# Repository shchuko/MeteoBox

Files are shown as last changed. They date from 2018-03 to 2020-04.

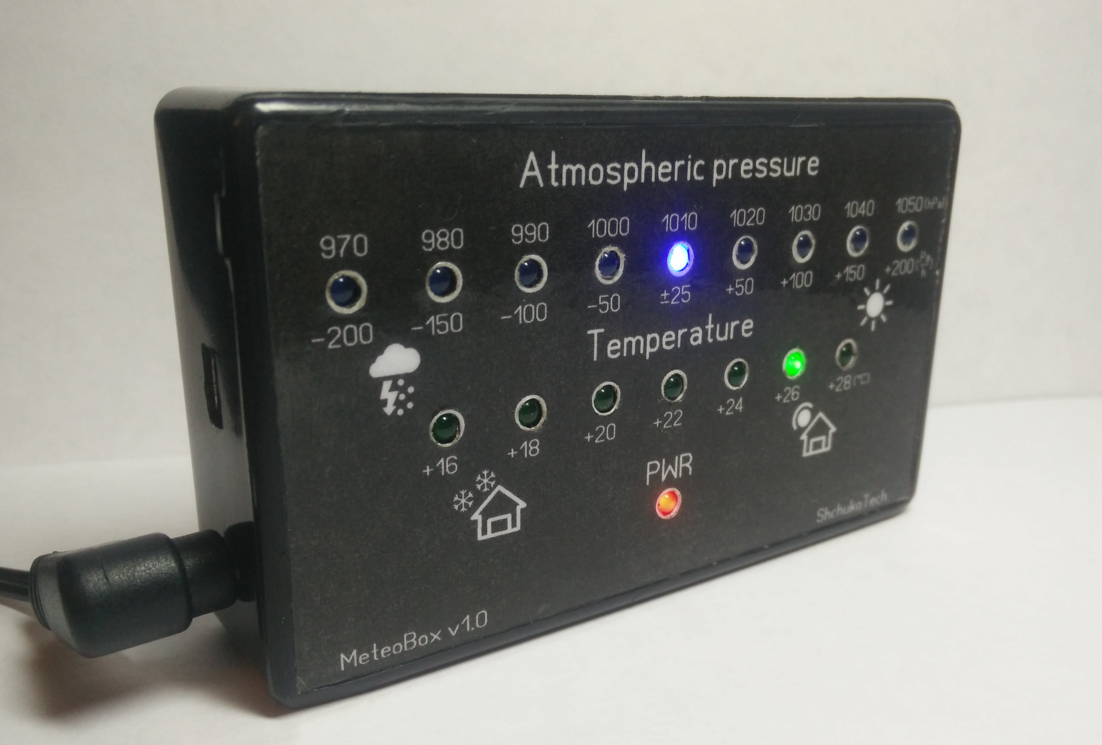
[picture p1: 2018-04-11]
images/1.jpg

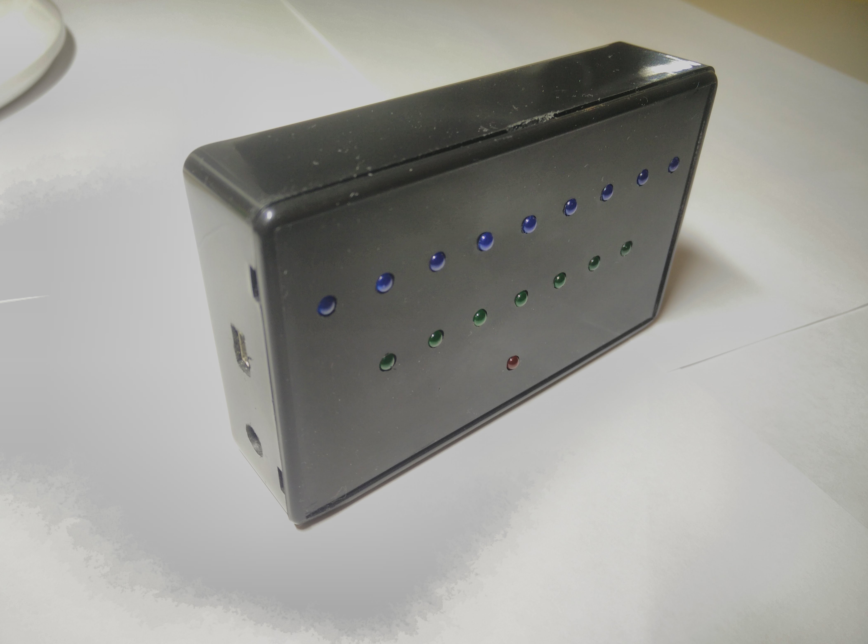
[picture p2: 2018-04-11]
images/3.jpg

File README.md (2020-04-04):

# MeteoBox
##### Simple Arduino-based weather predictor (pressure change tendention calculator). 
------

------
## Device functions
- Display current value of atmospheric pressure (in the range from 970 to 1050 hPa)
- Display current atmospheric pressure change tendention (in the range from -225 Pa/h to +225 Pa/h)
- Display of ambient temperature (in the range from +16°C to +28°C)
- Display of archive readings: atmospheric pressure,  atmospheric pressure change tendention (readings that was made 60 minutes ago)

## More information, user guide

[Uploaded to project wiki](https://github.com/shchuko/MeteoBox/wiki)

## Files

`images/` — Device photos

`src/libs/` — Arduino libraries

`src/sketch/` — Well-commented source code 

`pcbs/` — PCBs drawings, also including components list

`print_templates/` — Front panel and insulator print templates

## Installation
- Install [Arduino IDE](https://www.arduino.cc/en/Main/Software)
- Install [Optiboot bootloader](https://github.com/Optiboot/optiboot#to-install-into-the-arduino-software) into the Arduino software 
- [Burn Optiboot bootloader onto your Arduino Nano board](https://github.com/Optiboot/optiboot#to-burn-optiboot-onto-an-arduino-board)*
- Install the libraries `src/libs/` into the Arduino software 
- Flash the sketch `src/sketch/` into the Arduino board using Arduino IDE
- Connect the the rest of electronic components from the list `pcbs/Full components list.txt`. You can use PCBs or Bread board for this. I did not make a circuit, but using PCB drawings it's easy to figure out the connection of electronic components
- Power the board on!

*if you don't have an ability to burn Optiboot bootloader, comment out this lines in the source code:
```c
#include <avr/wdt.h> // Avr watchdog timer library 
wdt_disable( );
wdt_enable( WDTO_8S ); // setting up watchdog timer 
wdt_reset( ); // resetting watchdog timer
```

## Links
[Optiboot bootloader](https://github.com/Optiboot/optiboot)

[Arduino Software](https://www.arduino.cc/en/Main/Software)

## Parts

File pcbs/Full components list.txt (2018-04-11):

Components: controller

1. BMP180 Barometer
2. C1 100mkF
3. C2 0.1 mkF
4. D1 Nano v3
5. G1 DC Jack
6. LDR1  
7. R0 10k (SMD)
8. SB1 TTP223
9. SB2 RST
10. X1

Components: indication

1. LED1 Blue
2. LED2 Blue
3. LED3 Blue
4. LED4 Blue
5. LED5 Blue
6. LED6 Blue
7. LED7 Blue
8. LED8 Blue
9. LED9 Blue
10. LED10 Green
11. LED11 Green
12. LED12 Green
13. LED13 Green
14. LED14 Green
15. LED15 Green
16. LED16 Green
17. LED17 Red
18. R1 6.8k
19. R2 6.8k
20. R3 6.8k
21. R4 6.8k
22. R5 6.8k
23. R6 6.8k
24. R7 6.8k
25. R8 6.8k
26. R9 6.8k
27. R10 20k
28. R11 20k
29. R12 20k
30. R13 20k
31. R14 20k
32. R15 20k
33. R16 20k
34. R17 3.3k

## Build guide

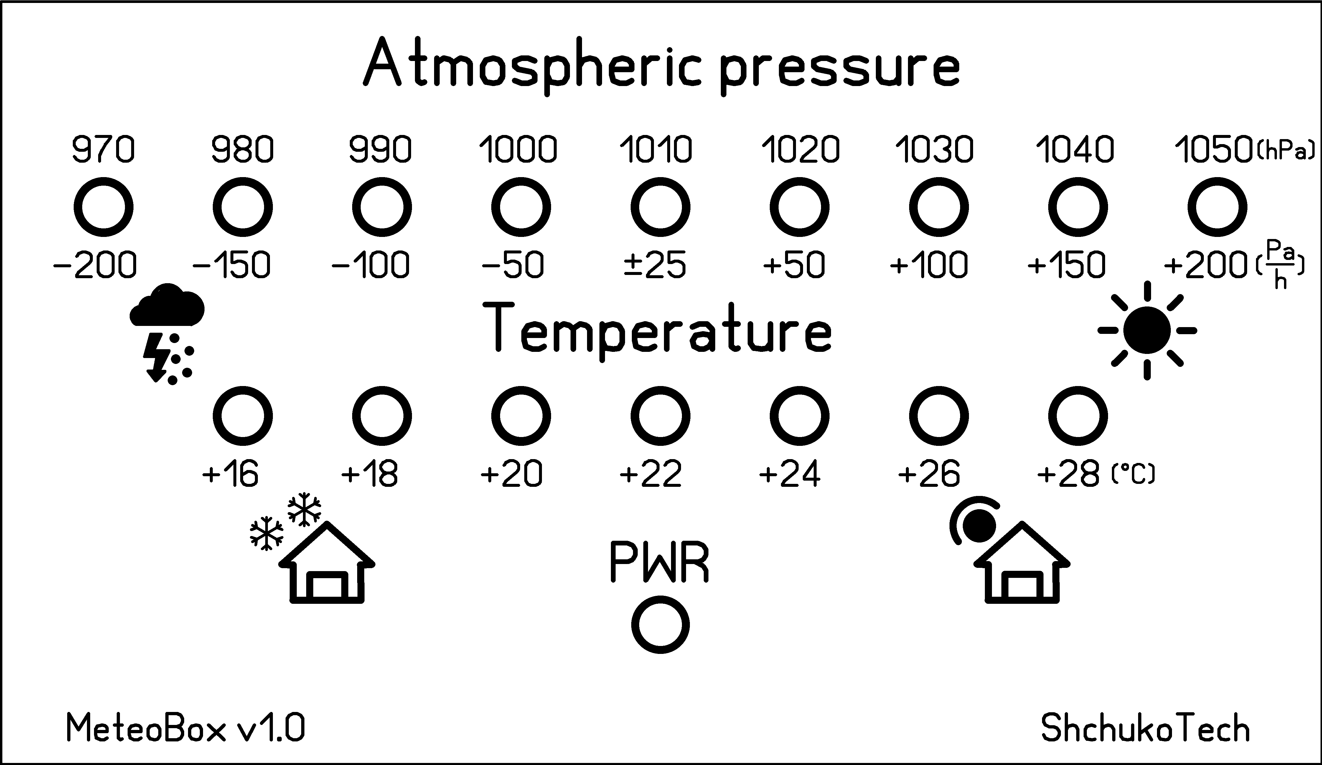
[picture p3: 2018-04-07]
print_templates/front_panel/bmp/front_panel_inv.bmp

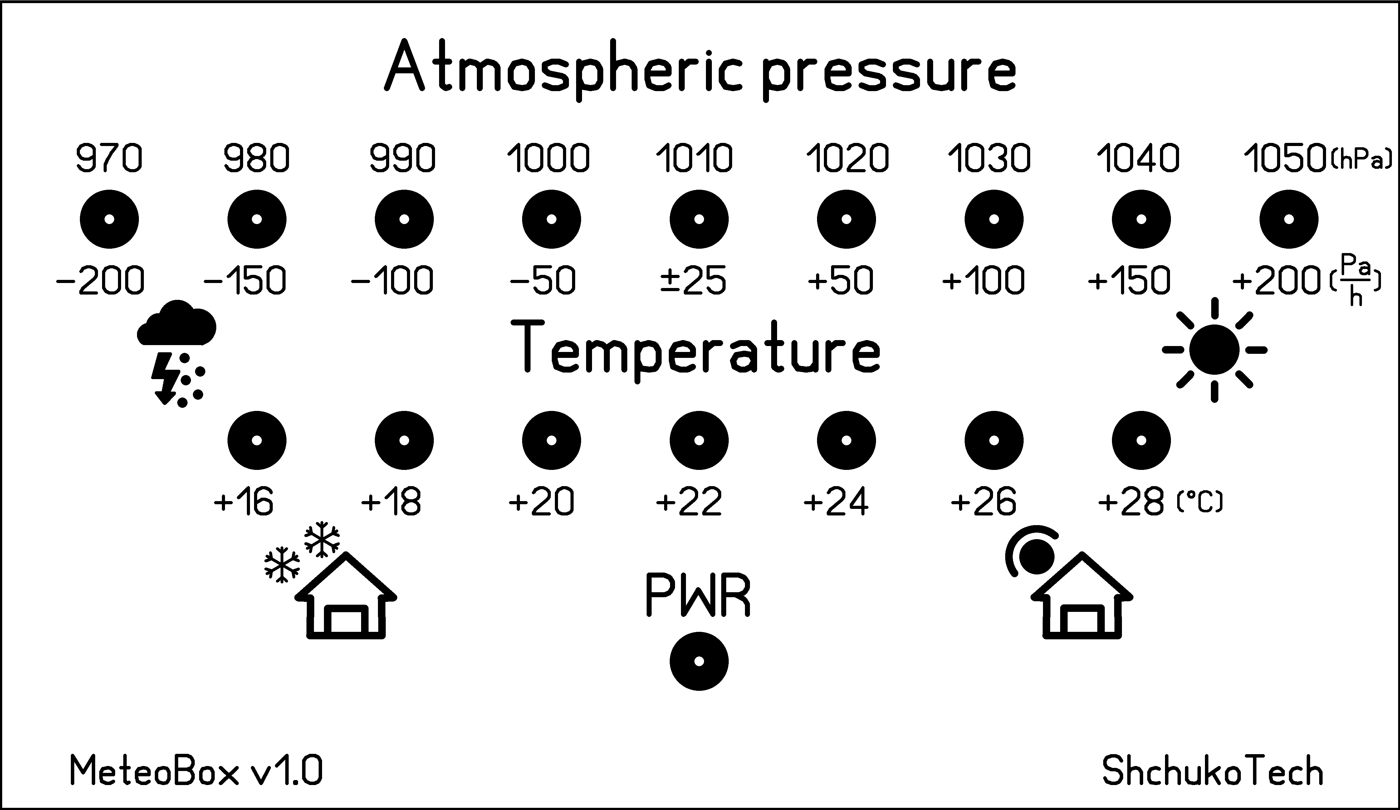
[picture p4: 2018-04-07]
print_templates/front_panel/bmp/front_panel_drill_inv.bmp

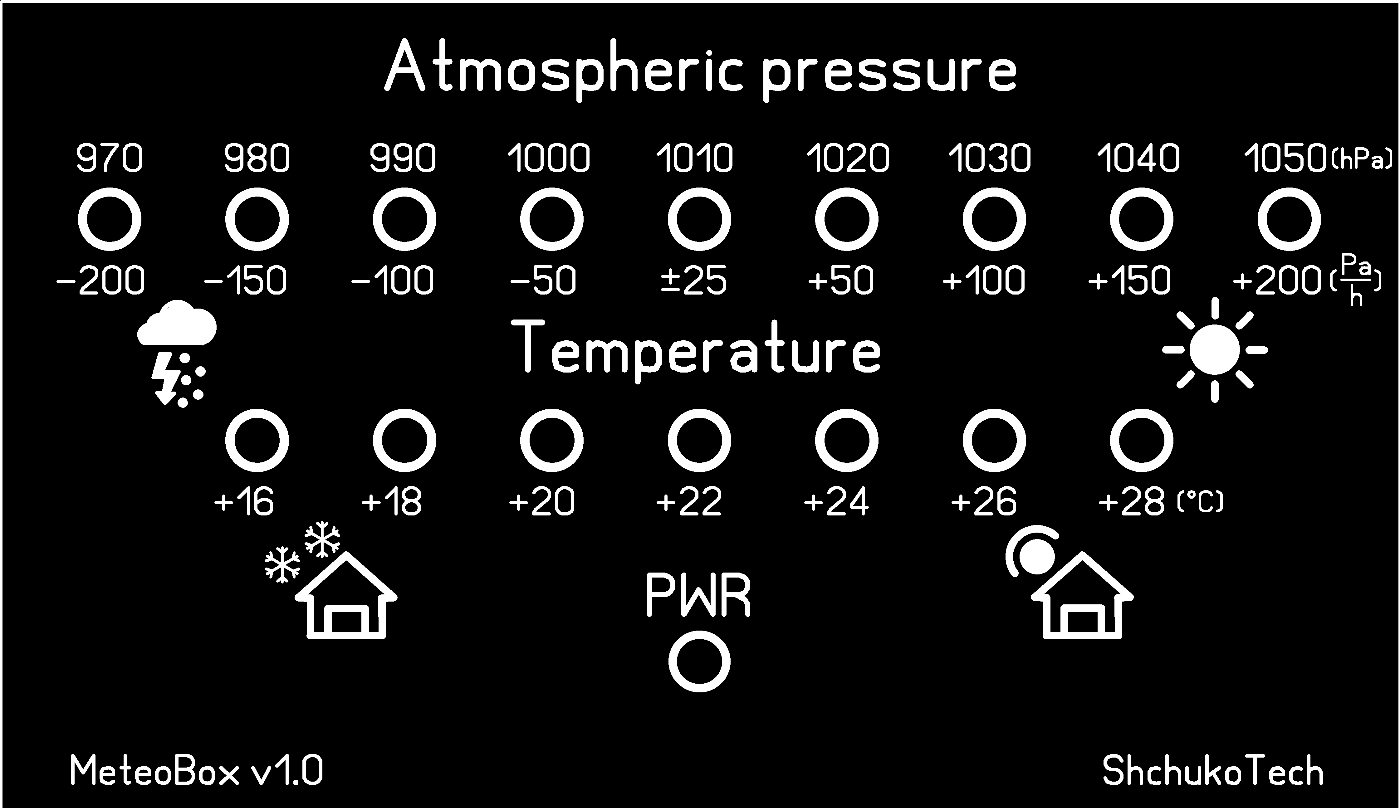
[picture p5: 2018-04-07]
print_templates/front_panel/bmp/front_panel.bmp

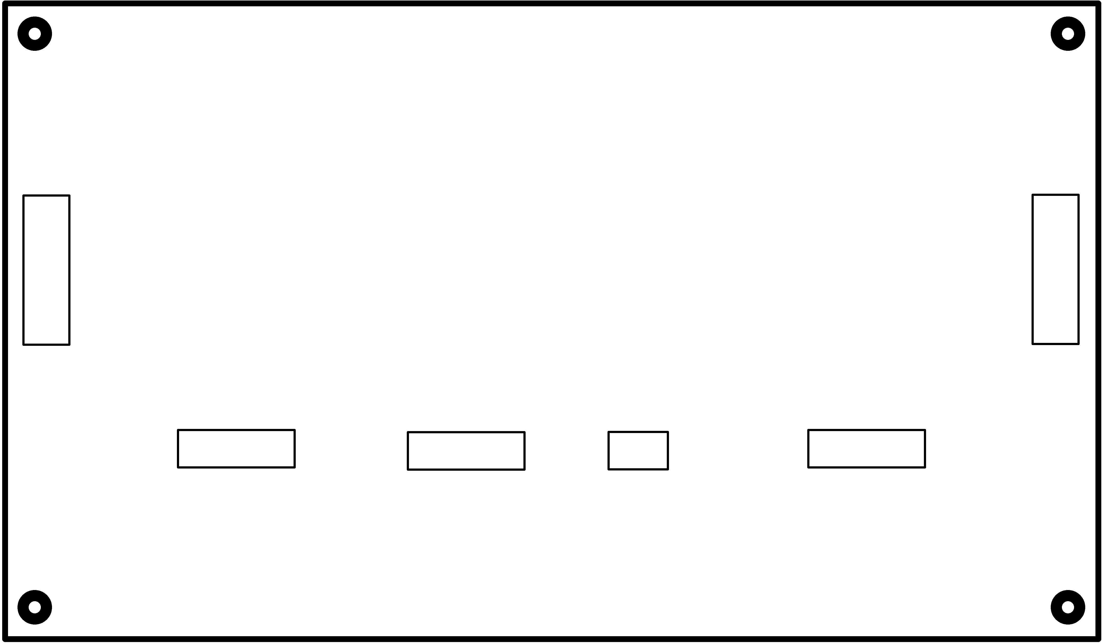
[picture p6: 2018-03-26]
print_templates/insulator/bmp/insulator_96x56mm.bmp

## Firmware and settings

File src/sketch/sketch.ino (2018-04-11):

/* MeteoBox  
 *  Version: 1.0.2
 *  Author: Vladislav Yaroshchuk (Shchuko)
 *  Created: 2018
 *  Website: https://github.com/shchuko 
 *  
 *  11/04/2018 shchuko: Watchdog timer added. Bug fixes
 *                     
 */

/* PIN CONFIGURATION
 *   D1:  L PWR 
 *   D0:  L +22*C
 *   D2:  L +-25 Pa/h (also: 1010hPa)
 *   D3:  TTP223 BUTTON 
 *   D4:  L +50 Pa/h (also: 1020hPa)
 *   D5:  L +100 Pa/h (also: 1030hPa)
 *   D6:  L +150 Pa/h (also: 1040hPa)
 *   D7:  L +200 Pa/h (also: 1050hPa)
 *   D8:  L -50 Pa/h (also: 1000hPa)
 *   D9:  L -100 Pa/h (also: 990hPa)
 *   D10: L -150 Pa/h (also: 980hPa)
 *   D11: L -200 Pa/h (also: 970hPa)
 *   D12: L +16*C
 *   D13: L +18*C
 *   D14: L +20*C
 *   D15: L +24*C
 *   D16: L +26*C
 *   D17: L +28*C
 *   A4: I2C BUS
 *   A5: I2C BUS
 *   A6: N/C
 *   A7: Light-dependent resistor (LDR)
 * L - LED
 * N/C - Not connected
 */

#include <Adafruit_BMP085.h>  // Barometr BMPxxx library
#include <EEPROM.h> // EEPROM library
#include <avr/wdt.h>  // Avr watchdog timer library

// -----Temperature indication pins-----
#define L_16C   12 
#define L_18C   13
#define L_20C   14
#define L_22C   0
#define L_24C   15
#define L_26C   16
#define L_28C   17

// -----Pressure indication pins----
#define L_25P   2 
#define L_50P   4
#define L_100P  5
#define L_150P  6
#define L_200P  7
#define L_50PM  8
#define L_100PM 9
#define L_150PM 10
#define L_200PM 11

// -----Pressure forecast-----
#define FORECAST_VAL_NUMBER       7   // Number of saved values
#define DATA_UPDATE_INTERVAL      5   // ... in minutes 
#define FORECAST_UPDATE_INTERVAL  10  // ... in minutes
                                      // Condition: FORECAST_UPDATE_INTERVAL % DATA_UPDATE_INTERVAL = 0 !!!

// -----Other-----
#define LDR     A7  // Light-dependent resistor
#define L_PWR   1   // Power LED
#define Pa_to_hPa 0.01 
#define NIGHT_FLAG_EEPROM_ARRD 0

// -----Controll button preferences-----
#define BT1_PIN  3 // Interrupt number
#define L_PWR_BTN_BLINK_NUMBER 4 // PWR LED blinks count if button was touched

// -----Classes------
class LedString { // LED string class 
                  // Contains methods for controlling the 
                  // LED string connected to the digital pins (max is 255)
private:

  uint8_t*  LED_string  = NULL;
  uint8_t*  pins = NULL;
  uint8_t   number = 0;

  uint8_t byte_num( uint8_t pin_num ) { // byte number in allocated memory
    pin_num++;
    return ( pin_num / 8 + ( pin_num / 8.0 > pin_num / 8 ) - 1 );
  }

  uint8_t bit_pos( uint8_t pin_num ) {  // bit position in byte 
    return ( pin_num - pin_num / 8 * 8 ); 
  }
  
public: 

  LedString( uint8_t _number ) {
    number = _number; // saving the number of LEDs
    pins = new uint8_t[ number ];  // allocate memory for pins numbers

    uint8_t byte_number = _number / 8 + ( _number / 8.0 > _number / 8 );  // calculating a sufficient number of memory (in bytes)
    LED_string = new uint8_t[ byte_number ]; // allocate memory for pins states
    
    for ( uint8_t i = 0; i < byte_number; i++ ) // clearing the memory
      LED_string[ i ] = 0;  
  } 

  ~LedString( ) { // never-called destructor ;)
    delete[ ] pins;
    pins = NULL;

    delete[ ] LED_string;
    LED_string = NULL;
  }
  void init_pin( uint8_t pin_arduino, uint8_t pin_num ) {
    pinMode( pin_arduino, OUTPUT ); // set pin mode as OUTPUT 
    digitalWrite( pin_arduino, 0 ); // set pin state as "0"
   
    pins[ pin_num ] = pin_arduino;
  }
  
  bool get_pin( uint8_t pin_num ) { // returns pin state
    return ( ( LED_string[ byte_num( pin_num ) ] >> bit_pos( pin_num ) ) & ( 1 << 0 ) );
  }
 
  void set_pin( uint8_t pin_num, bool pin_state ) { // set state for pin
    bool old_pin_state = get_pin( pin_num );
    
    if ( pin_state != old_pin_state ) {
      digitalWrite( pins[ pin_num ], pin_state );
      
      if ( pin_state )  // if new state is "1" writing...
        LED_string[ byte_num( pin_num ) ] |= ( 1 << bit_pos( pin_num ) );
      else  // else if new state is "0" writing...
        LED_string[ byte_num( pin_num ) ] &= ~( 1 << bit_pos( pin_num ) );
    }
    
  }

  uint8_t get_byte( uint8_t _byte_num ) { // returns full byte
    return LED_string[ _byte_num ];
  }
  
  void set_byte( uint8_t _byte_num, uint8_t new_byte ) { // set full byte 
    if ( new_byte != LED_string[ _byte_num ] ) {
      LED_string[ _byte_num ] = new_byte;
      for ( uint8_t i = 0; i < 8; i++ )
        if ( 8 * _byte_num + i < number )
          digitalWrite( pins[ 8 * _byte_num + i ],(( new_byte >> i ) & ( 1 << 0 )) );
        else
          break;
    }
  }

  void on( ) {
    for ( uint8_t i = 0; i < number; i++ ) {
      if ( !(i % 8) ) 
         LED_string[ i / 8 ] = 0xFF;
      digitalWrite( pins[ i ],  1 );
    }
  }

  void off( ) {
    for ( uint8_t i = 0; i < number; i++ ) {
      if ( !(i % 8) ) 
         LED_string[ i / 8 ] = 0;
      digitalWrite( pins[ i ],  0 );
    }
  }
  
};

class MedianFilter {  // Median filter class ( all arguments > 0 )
private:
  uint32_t *values = NULL; // pointer at the first saved value
  uint8_t val_number = 0; // number of values
  
  uint8_t new_val_pos = 0;  // position of new value in values[ ] ( used in function new_val )
  
  uint32_t result = 0; // result value 

  void calculate( ) { // calculating median value
    // bubble sort algorithm
    for( uint8_t i = 0; i < val_number - 1; i++ )  
      for( uint8_t j = i + 1; j < val_number; j++ )
      { 
        if( values[ i ] > values[ j ] )
        {
          uint32_t term_val = values[ i ];
          values[ i ] = values[ j ];
          values[ j ] = term_val;
        }
      }
    result = values[ ( uint8_t )(( val_number - 1 ) / 2 ) ]; // saving median value
  }
  
public:
  MedianFilter( uint8_t _val_number ) {
    val_number = _val_number; // saving the number of values
    values = new uint32_t[ _val_number ]; // allocate memory for saving values    
  }

  ~MedianFilter( ) {  // never-called destructor
    delete[ ] values;
    values = NULL;
  }
  void init( uint32_t val ) {
    for ( uint8_t i = 0; i < val_number; i++ )
      values[i] = val;
    result = val;
  }
  
  bool new_val( uint32_t val ) { // updating (saving) new value
                                        // returning 1 - updating complete, 0 - updating not complete 
      values[ new_val_pos ] = val; // saving new value
      new_val_pos++; // incriminate value pos counter
    if ( new_val_pos == val_number )  // if all values saved
    {
      new_val_pos = 0; 
      calculate( ); // calculating median value
      return 1; // returning 1
    } 
    // else 
    return 0; // returning 0
  } 

  uint32_t get_result( ) {  // returning calculated median value
    return result;
  }

};

class PressureForecast {
private:
  uint32_t   *pressure = NULL;        // pointer for dynamic memory allocation for pressure
  int16_t    *history  = NULL;        // pointer for dynamic memory allocation for forecast history
  int16_t    change_hour;             // pressure change forecast (Pa/h)
  uint8_t    measurement_number;       // measurement number used for calculating forecast
  uint16_t   measurement_interval;    // pressure update interval (in minutes)
  uint8_t    meas_updts_counter = 1;  // pressure updates counter
  
  void calculate( ) {   // pressure change calculatioin
                        // using least squares fit
    uint32_t sumx = 0;  
    uint32_t sumy = 0;
    uint32_t sumx2 = 0;
    uint32_t sumxy = 0;
    for ( uint8_t i = 0; i < measurement_number; i++ ) {
      sumx += i;
      sumy += pressure[ i ];
      sumx2 += i * i;
      sumxy += i * pressure[ i ];
    }
    double a;
    a = measurement_number * sumxy;
    a -= sumx * sumy;
    a = ( double )a / ( measurement_number * sumx2 - sumx * sumx );
    change_hour = round( a * 60 / measurement_interval ); // pressure change forecast (Pa/h)
  }
  
public:
  void set( uint32_t _pressure ) {  // set new pressure value
    for ( uint8_t i = 0; i < measurement_number - 1; i++ ) {// shifting old saved values
      pressure[ i ] = pressure[ i + 1 ];  
      history[ i ] = history[ i + 1 ];
    }
    pressure[ measurement_number - 1 ] = _pressure;  // saving new value
    calculate( ); // re-calculating  forecast
    
    history[ measurement_number - 1 ] = change_hour;
    
    if ( meas_updts_counter < measurement_number )  // if full update did not complete
      meas_updts_counter++; 
  }

  bool is_update( ) {  // returns 1 if full update completed
    return ( meas_updts_counter >= measurement_number );
  }
  
  int16_t get_history_forecast( ) { // returns forecast history value
    return history[ 0 ];
  }

  uint32_t get_history_pressure( ) { // returns pressure history value
    return pressure[ 0 ];
  }

  int32_t get_forecast( ) { // returns pressure change forecast (Pa/h)
    return change_hour;
  }
  
  void begin( uint32_t _pressure )  // set first pressure value (in Pa)
  {
    for ( uint8_t i = 0; i < measurement_number; i++ ) {
      pressure[ i ] = _pressure;
      history[ i ] = 0;
    }
  }
  
  PressureForecast( uint8_t  _measurement_number,         // measurement number used for calculating forecast
                     uint16_t  _measurement_interval ) {  // pressure update interval (in minutes)
    // dynamic memory allocation
    pressure = new uint32_t [ _measurement_number ];
    history = new int16_t [ _measurement_number ];
    
    measurement_number = _measurement_number;
    measurement_interval = _measurement_interval;
  }  

  ~PressureForecast( ) {  // never-called destructor ;)
    delete[ ] pressure;
    delete[ ] history;

    pressure = NULL;
    history = NULL;
  }
  
};

class TTP223 {  // TTP223 sensor click handler
                // based on  millis( ) func.
                // Three modes of recognition of button pressing:
                // [short click], [double click], [long press]
private:
  void ( *long_press )( void );    // pointer to a long-press action function 
  void ( *short_click )( void );   // pointer to a short-click action function
  void ( *double_click )( void );  // pointer to a double-click action function
    
  uint8_t pin = 0;  // pin number

  bool touch_flag = 0;  
  bool double_click_flag = 0;
  
  bool last_state = 0;
  
  uint64_t press_time = 0; // last button touching time 

public:
  
  TTP223( uint8_t _pin,                     // interrupt number (0 or 1)
          void ( *_short_click )( void ),   // pointer to the button short-click function
          void ( *_double_click )( void ),  // pointer to the button double-click function
          void ( *_long_press )( void ) ) { // pointer to the button long-press function
    short_click  = _short_click; 
    double_click = _double_click;
    long_press   = _long_press;
   
    pin = _pin;
  }

  ~TTP223 ( ) { // never-called destructor ;)
    short_click = NULL;
    double_click = NULL;
    long_press = NULL;
  }

  void loop_func( ) { // button click handler
    if ( digitalRead( pin ) != last_state ) { // if buton pin state have changed
      last_state = !last_state; // saving new state

      if ( last_state ) { // if button pressed
        press_time = millis( ); // saving button press time
        touch_flag = 1; // press (click) flag
      } 
    }
    
    if ( touch_flag && millis( ) - press_time > 700 ) {  // if 700 ms least after last click
      long_press( );  // long-press function
      touch_flag = 0; 
    }

    if ( double_click_flag && millis() - press_time  > 400 ) {  // if double-click time has expired 
                                                                // (it's not enough time to double-click
                                                                // - more than 400 ms left)
      double_click_flag = 0;                                   
                
      short_click( ); // short-click function
    }
    
    if ( touch_flag ) // if the button was pressed
      if ( double_click_flag ) {  // if double-click is possible
        double_click_flag = 0;  
        touch_flag = 0; 
        double_click( );  // double-click function
        
      } else if ( !last_state ) { // else if button was released
        touch_flag = 0;
          
        if ( millis( ) - press_time <= 400 ) // if it's enough time to double-click 
          double_click_flag = 1;  // setting up double-click flag
        else // else if it's not enough time to double-click
          short_click( ); // short-click function
      }
  }
};

// -----Button functions-----
void button_long_press( );
void button_short_click( );
void button_double_click( );

// -----Objects------
LedString prs_led( 9 ); // pressure indication string - 9 LEDs
LedString temp_led( 7 );  // temperature indication string - 7 LEDs

Adafruit_BMP085 bmp;  // BMPxxx sensor
PressureForecast forecast( FORECAST_VAL_NUMBER, FORECAST_UPDATE_INTERVAL );  //  pressure change forecast

MedianFilter avr_pressure( 10 );  // median filter for BMP180 barometer data - 10 values save
MedianFilter avr_luminosity( 10 );  // median filter for light-dependent resistor data - 10 values save

TTP223 button( BT1_PIN, button_short_click, button_double_click, button_long_press ); // TTP223 button

// -----Global variables-----
uint32_t pressure = 0;       // current pressure in hPa
int16_t  temperature = 0;    // current temperature in *C
uint16_t luminosity = 1023;  // current illumination value (from ADC: 0..1023)

bool     _forecast_actual_flag = 0;      // forecast actual flag

uint8_t  _forecast_range = 4;            // forecast range (for LED string)
uint8_t  _forecast_range_blink_mode = 4; // forecast blink mode 

uint8_t  _forecast_h_ago_range = 4;            // forecast range 1 hour ago (for LED string)
uint8_t  _forecast_h_ago_range_blink_mode = 4; // forecast blink 1 hour ago mode 

uint8_t  _pressure_range = 4;            // pressure range (for LED string)
bool     _pressure_range_blink_flag = 0; // pressure range blink flag

uint8_t  _pressure_h_ago_range = 4;            // pressure range 1 hour ago (for LED string)
bool     _pressure_h_ago_range_blink_flag = 0; // pressure range 1 hour ago blink flag

uint8_t  _temp_range = 3;            // temperature range (for LED string)
bool     _temp_range_blink_flag = 0; // temperature range blink flag

bool night_mode_enable = 1; // night mode flag (0 - enable, 1 - disable)
bool night_mode_state = 0;  // current situation flag (0 - LEDs enable, 1 - LEDs disable)

bool     temprary_touch_awake = 0; // system awaking from the night mode if button touched
uint64_t temprary_touch_awake_counter = 0;  

bool display_mode = 0;  // genegal diplay mode
                        // 0 - current data, 1 - data 1h ago 
bool prs_disp_mode = 0; // pressure display mode
                        // 0 - current pressure (hPa), 1 - pressure forecast display (Pa/h)

uint64_t display_return_counter = 0;  // time counter to return to current 
                                      // data display & current pressure display
uint8_t  display_return_mode = 0; // return mode:
                                  // 0 - disable
                                  // 1 - return from forecast display to the current pressure display
                                  // 2 - return from 1h ago data display to the current data display

uint64_t button_blink_counter_time = 0; // button touch - PWR LED blink time counter
uint8_t  button_blink_counter = L_PWR_BTN_BLINK_NUMBER; // button touch - PWR LED blink(s) counter - max is L_PWR_BTN_BLINK_NUMBER

// -----Functions-----
void serial_test_func( ) {
  Serial.println( );
  Serial.println( "******************************" );
  Serial.println( "Data update..." );
  Serial.println( );
  
  Serial.print( "Pressure: ");
  Serial.println( pressure );
  Serial.print(" Pressure range: ");
  Serial.println( _pressure_range );
  Serial.print(" Pressure range blink flag: ");
  Serial.println( _pressure_range_blink_flag );

  Serial.print( "Temperature: ");
  Serial.println( temperature );
  Serial.print(" Temperature range: ");
  Serial.println( _temp_range );
  Serial.print(" Temperature range blink flag: ");
  Serial.println( _temp_range_blink_flag );

  Serial.print( "Forecast: " );
  Serial.println( forecast.get_forecast( ) );
  Serial.print( " Forecast actual flag: " );
  Serial.println( _forecast_actual_flag );
  Serial.print( " Forecast range: " );
  Serial.println( _forecast_range );
  Serial.print( " Forecast range blink mode: " );
  Serial.println( _forecast_range_blink_mode );
  
}

void serial_flag_test_func( ) {
  Serial.println( );
  Serial.println( "******************************" );
  Serial.println( "Button touched..." );
  Serial.println( );
  
  Serial.print( "Night mode enable flag: " );
  Serial.println( night_mode_enable );

  Serial.print( "Display mode flag: " );
  Serial.println( display_mode );
  
  Serial.print( "Pressure display mode flag: " );
  Serial.println( prs_disp_mode );
}

void button_short_click( ) {
  button_blink_counter = 0; // setting buton blink counter to zero
  digitalWrite( L_PWR, 1 ); // switching on PWR LED
  
  if ( !night_mode_state || temprary_touch_awake )  // if LEDs are enabled or it is temprary awake
  {
    prs_disp_mode = !prs_disp_mode;
    
    if ( display_mode ) { // if it is 1h ago data display 
      
      display_return_mode = 2;  // changing return timer mode 
      display_return_counter = millis( ); // updating time counter
    } 
  
    if ( prs_disp_mode && !display_mode ) {  // if it's switching to the forecast display mode within current data display
      display_return_mode = 1;  // changing return timer mode 
      display_return_counter = millis( ); // updating time counter
    } else if ( display_return_mode && !display_mode ) {  // else if it's current data display within enabled return timer
      display_return_mode = 0;  // disabling timer
    }

    // if it's it is temprary awake, updating awake timer
    if ( temprary_touch_awake ) temprary_touch_awake_counter = millis( );
    
  } else if ( night_mode_state && night_mode_enable ) { // else if luminosity is low, LEDs are disabled
    display_mode = 0; // switching to the  current data fisplay
    prs_disp_mode = 0;  // switching pressure display mode to the pressure mode
    
    temprary_touch_awake = 1; // waking up system for several seconds
    temprary_touch_awake_counter = millis( );
  } 
  
  temp_led.off( );  // clearing temperature LED string
  prs_led.off( );   // clearing pressure LED string
  //serial_flag_test_func( );
}

void button_double_click( ) { 
  button_blink_counter = 0; // setting buton blink counter to zero
  digitalWrite( L_PWR, 1 ); // switching on PWR LED
  
  if ( ( !night_mode_state || temprary_touch_awake ) && _forecast_actual_flag )  // if LEDs are enabled or it is temprary awake
  {                                                                              // and 1h left after powering on system
    prs_disp_mode = 0;  // switching pressure display mode to a pressure mode
    
    if ( display_mode = !display_mode ) { // if it is switching to 1h ago data display 
      display_return_mode = 2;  // changing return timer mode 
      display_return_counter = millis( ); // updating time counter
    } else {
      display_return_mode = 0;
    }

    // if it's it is temprary awake, updating awake timer
    if ( temprary_touch_awake ) temprary_touch_awake_counter = millis( );
    
  } else if ( night_mode_state ) { // else if luminosity is low, LEDs are disabled
    display_mode = 0; // switching to the  current data fisplay
    prs_disp_mode = 0;  // switching pressure display mode to the pressure mode
    
    temprary_touch_awake = 1; // waking up system for several seconds
    temprary_touch_awake_counter = millis( );
  } 
  
  temp_led.off( );  // clearing temperature LED string
  prs_led.off( );   // clearing pressure LED string
  //serial_flag_test_func( );
}
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
void loop( ) {
  wdt_reset( ); // resetting watchdog timer
  
  button.loop_func( ); 
  
  luminosity_upd( luminosity ); //updating luminosity
  
  // nigth mode switcher with gisteresis:
  if ( night_mode_enable ) {
    if ( luminosity < 95 )  // if luminosity is low
      night_mode_state = 1;
    else if ( luminosity > 127 )  // if luminosity is high
      night_mode_state= 0;
  } else if ( night_mode_state ) {
    night_mode_state = 0;
  }

  static uint64_t data_upd_counter = millis( ); // data update time counter  
  static uint64_t forecast_upd_counter = millis( ); // data update time counter

  
  if ( millis( ) - data_upd_counter  >= DATA_UPDATE_INTERVAL * 60000 ) { // if it's time to update data 
    pressure = pressure_upd( );  // updating pressure
    _pressure_range = pressure_range( round( pressure * Pa_to_hPa ), _pressure_range_blink_flag ); // updating pressure range
    
    temperature = round( bmp.readTemperature( ) - 3 ); // updating temperature
    _temp_range = temp_range( temperature, _temp_range_blink_flag );  // updating temperature range

    
    if ( millis( ) - forecast_upd_counter >= FORECAST_UPDATE_INTERVAL * 60000 ) {  // if it's time to update forecast
      forecast.set( pressure ); // updating forecast
      _forecast_actual_flag = forecast.is_update( );  // updating forecast actuality flag
      _forecast_range = forecast_range( forecast.get_forecast( ), _forecast_range_blink_mode ); // updating forecast range

      // updating history (1h ago) values:
      _forecast_h_ago_range = forecast_range( forecast.get_history_forecast( ), _forecast_h_ago_range_blink_mode );
      _pressure_h_ago_range = pressure_range( round( forecast.get_history_pressure( ) * Pa_to_hPa ), _pressure_h_ago_range_blink_flag );
      
      forecast_upd_counter = millis( );

      //Serial.println( "-----------Forecast update-----------" );
    }
    data_upd_counter = millis( ); // saving current time
    
    //serial_test_func( );
  }  
  
  led_display( ); // LED display func
}

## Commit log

2018-03-26 Added *.gbr Gerber files to PCBs templates. Added insulator print template
    [controller_C1_top.gbr, controller_C2_bot.gbr, controller_S1_top.gbr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]
2018-03-27 Added new class to handy interact with the LEDs. Bug fixes
    [sketch.ino]
2018-03-28 Controller PCB correction
    [controller_C2_bot.gbr, controller_S1_top.gbr, controller_S2_bot.gbr]
2018-04-02 PCBs final version
    [controller_C2_bot.gbr, controller_S1_top.gbr, indication_C2_bot.gbr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]
2018-04-04 PCBs editing: bugs fixed, components list added
    [controller_C2_bot.gbr, controller_S1_top.gbr, controller_S2_bot.gbr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]
2018-04-04 Moving indication PCB *.gbr files
    [indication_C2_bot.gbr, indication_S1_top.gbr]
2018-04-07 Added new class PressureForecast
2018-04-08 TTP223, LEDString classes upgrade
2018-04-09 Added algorithm of sensors data updating. Added system serial-test. Bug fixes
    [sketch.ino]
2018-04-10 LED indicastion display configured. Bug fixes
    [sketch.ino]
2018-04-10 Added night flag saving to EEPROM. Added forecast history saving. Bug fixes
    [sketch.ino]
2018-04-11 Watchdog timer added. Bug fixes
    [sketch.ino]
2018-04-11 Added PCBs *.bmp files
